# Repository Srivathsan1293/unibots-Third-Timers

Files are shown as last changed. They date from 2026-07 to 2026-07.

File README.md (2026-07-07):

Software architecture:

1. Phone handles position and long range ball detection.
2. Rasberry Pi 4 handles close range ball detection (0-20cm) and FSM communicating to both phone and ESP's
3. Encoder.ino runs on Drive_esp which handles wasd instrucitons using PID with IMU+encoder fusion.
4. Launcher.ino control launch sequence

The phone used is a pixel 7. 
The onboard TPU is used to accelerate ML inference to detect balls even 2m away.
Using focal length data and real world position the system determines robots position to a couple cm. 
Using exact position the position of balls is also estimated and shown on a map with the robot always moving towards the closest ball.

In order to maximise on day performance all variables can be adjusted quickly using a settings menu.

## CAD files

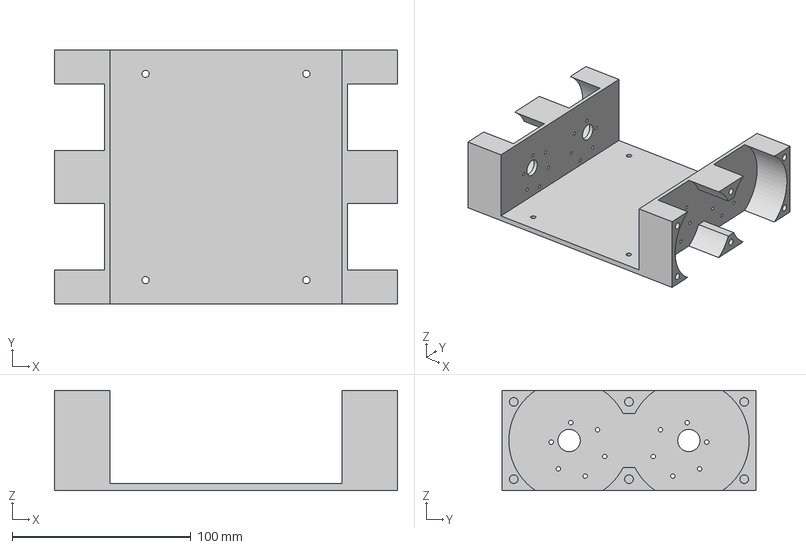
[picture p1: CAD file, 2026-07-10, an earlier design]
cad_old/early_june_prints/New Base.3mf
192.0 x 142.0 x 56.2 mm

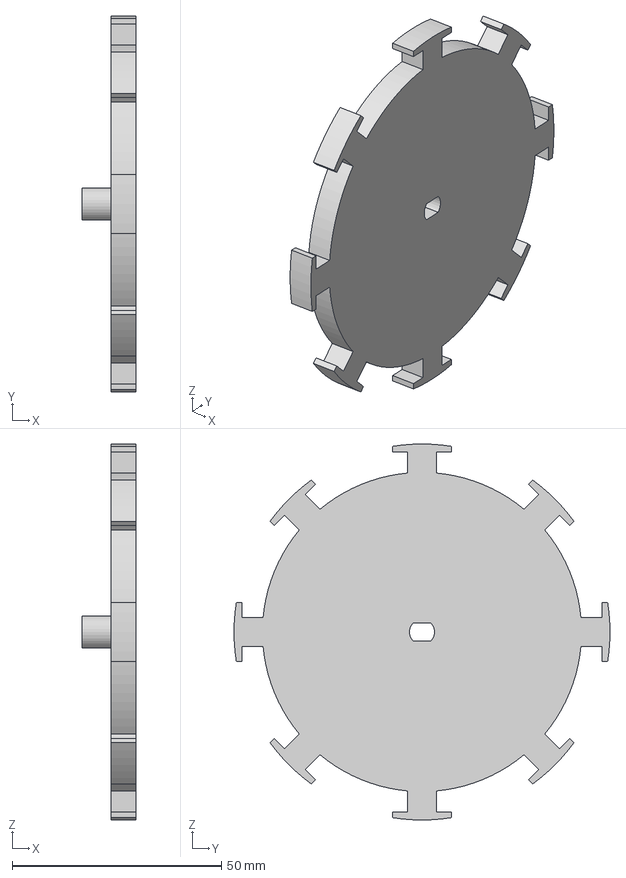
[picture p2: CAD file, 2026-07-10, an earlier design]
cad_old/late_may_prints/Spokes for Rubber Bands.3mf
13.0 x 89.9 x 89.9 mm

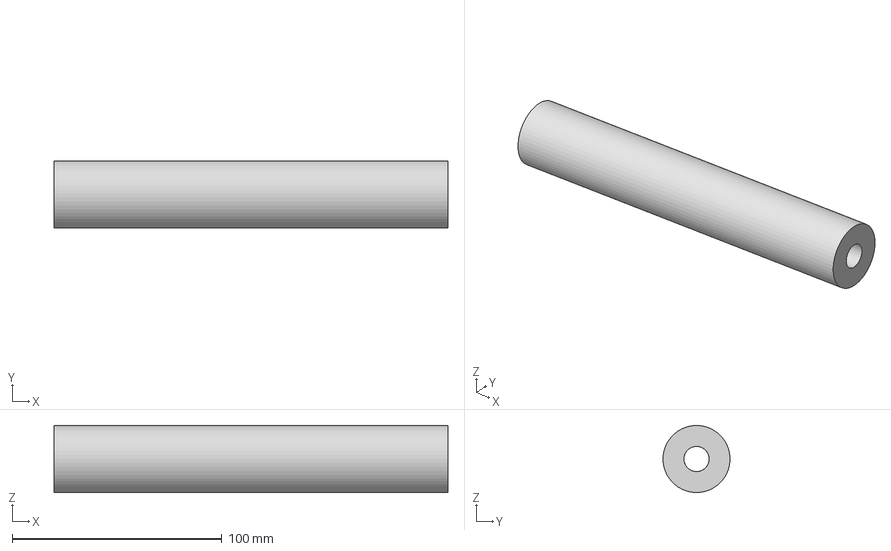
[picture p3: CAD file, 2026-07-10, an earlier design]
cad_old/middle.3mf
188.0 x 32.0 x 32.0 mm

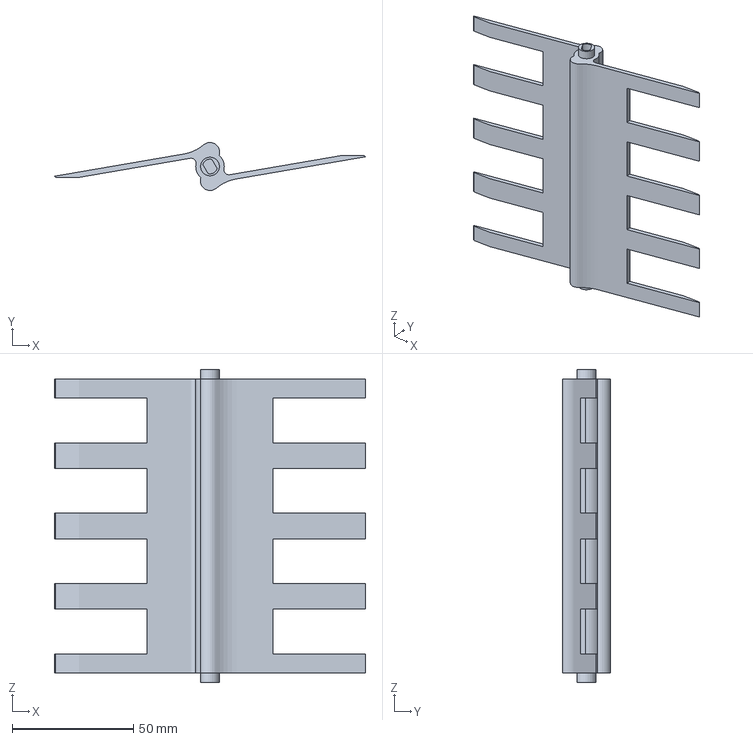
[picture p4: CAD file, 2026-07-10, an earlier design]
cad_old/early_june_prints/New Spin.3mf
128.0 x 19.8 x 129.0 mm

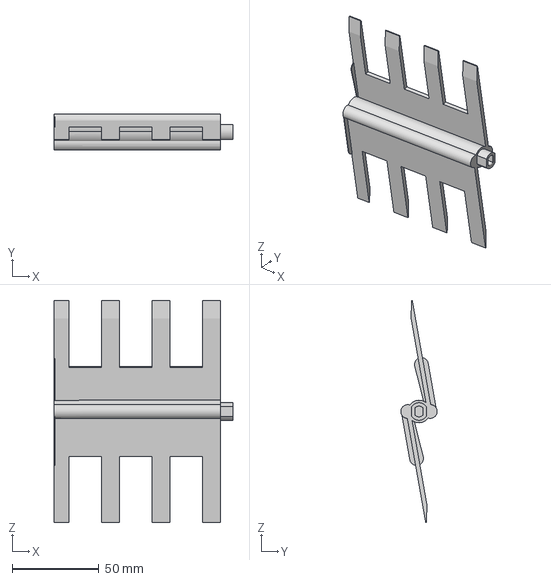
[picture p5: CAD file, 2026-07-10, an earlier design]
cad_old/late_may_prints/spin.3mf
103.0 x 21.0 x 128.0 mm

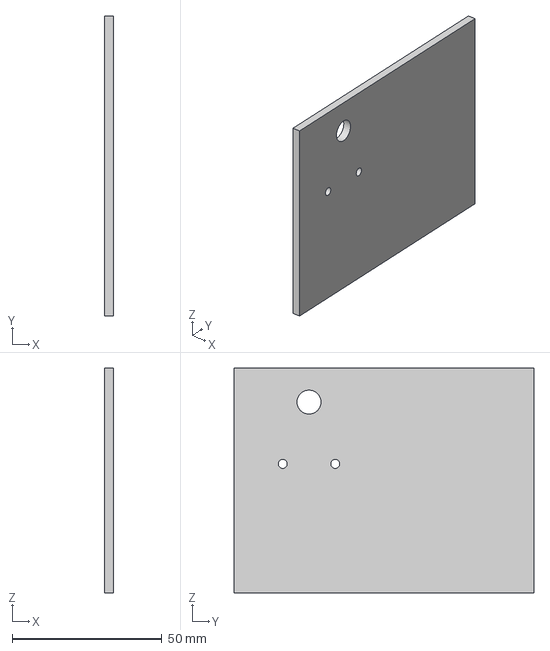
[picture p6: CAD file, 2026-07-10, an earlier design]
cad_old/Sidewall.3mf
3.00 x 100.0 x 75.0 mm

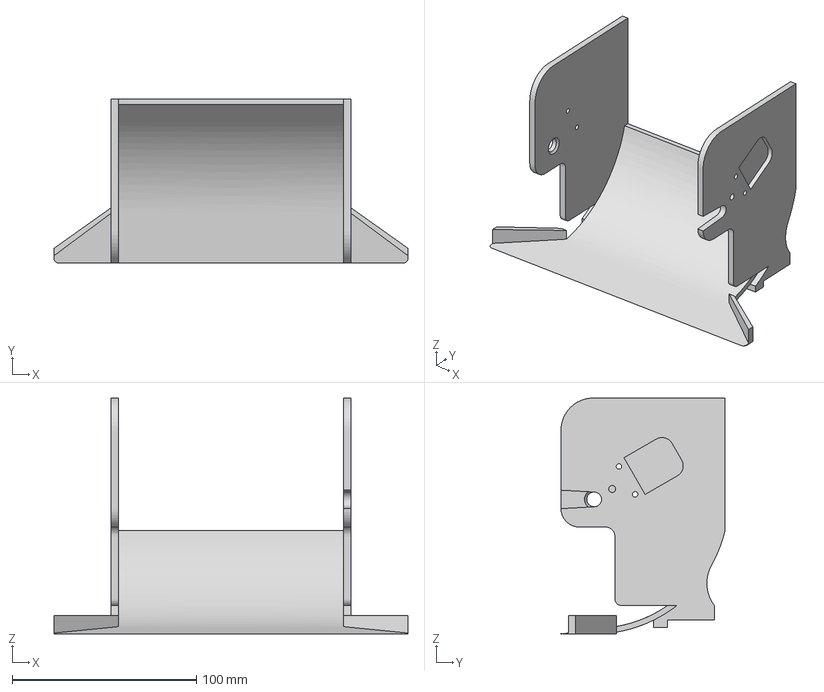
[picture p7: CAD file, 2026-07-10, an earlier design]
cad_old/early_june_prints/New Ramp.3mf
192.0 x 89.0 x 128.0 mm

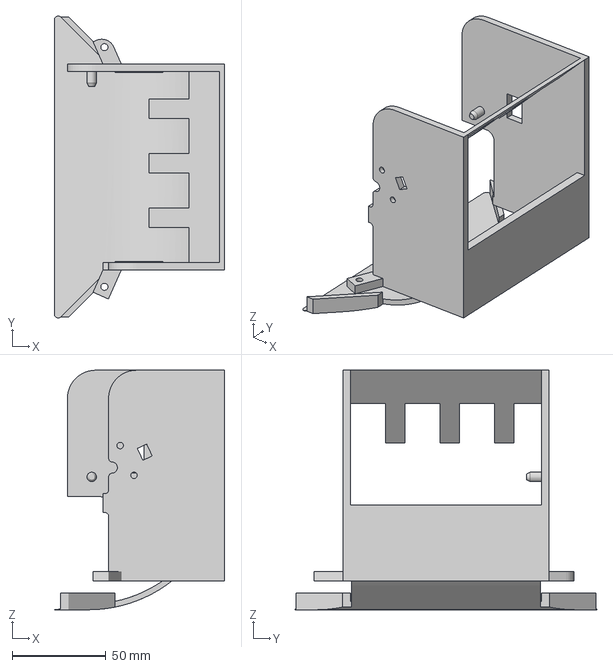
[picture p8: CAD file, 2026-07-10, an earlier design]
cad_old/late_may_prints/Slope.3mf
91.0 x 161.3 x 128.0 mm

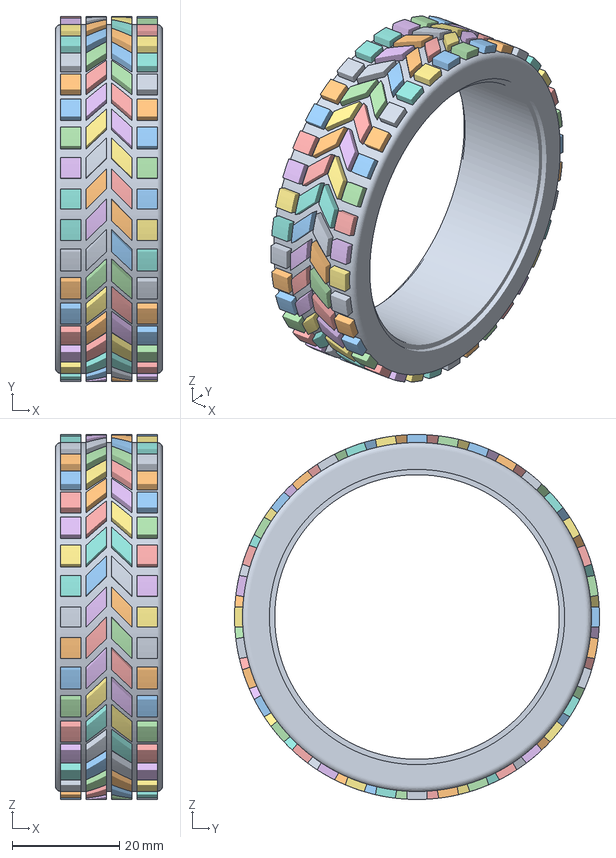
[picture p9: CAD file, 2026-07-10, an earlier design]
cad_old/Tyre.3mf
20.0 x 68.0 x 68.0 mm

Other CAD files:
cad_old/ramp-NEW_NEW.3mf
cad_old/Tyre.gcode.3mf
cad_old/Single_Tyre.gcode.3mf
cad_old/spin_new.3mf
cad_old/New Tyre.gcode.3mf

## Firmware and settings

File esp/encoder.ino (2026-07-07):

#include <Wire.h>
#include <Adafruit_MPU6050.h>
#include <Adafruit_Sensor.h>
#include <ESP32Encoder.h>

// =========================
// Pin Definitions
// =========================

// --- Drive Pins ---
const int FL_IN1 = 13, FL_IN2 = 14;
const int FR_IN2 = 12, FR_IN1 = 26; // FR_IN1 moved to 12
const int LR_IN3 = 27, LR_IN4 = 32;
const int RR_IN4 = 18, RR_IN3 = 33;

// --- PWM Pins ---
const int FL_PWM = 2;
const int FR_PWM = 5;
const int LR_PWM = 15;
const int RR_PWM = 22;

// --- Encoder Pins ---
const int FL_A = 34, FL_B = 35;
const int FR_A = 36, FR_B = 39;
const int RR_A = 4,  RR_B = 25; // RR swapped to 4 and 25
const int LR_PIN = 19;

// =========================
// PWM Setup
// =========================
const int PWM_FREQ = 20000;
const int PWM_RES_BITS = 8;

// =========================
// Encoder Objects
// =========================
ESP32Encoder encFL, encFR, encRR;
volatile long pulseCountLR = 0;

// =========================
// IMU Setup (For PID Correction ONLY)
// =========================
Adafruit_MPU6050 mpu;
float currentYaw = 17.0f; 
float gyroZOffset = 0.0f;
unsigned long lastImuTime = 0;

// =========================
// Drive State Machine & Control
// =========================
enum DriveState { STOPPED, FWD, REV, LEFT, RIGHT };
DriveState currentState = STOPPED;
DriveState pendingState = STOPPED;

float activeTargetPPS = 0.0f; 
float currentRampedPPS = 0.0f;
const float maxAccelPerLoop = 3000.0f; // Slew rate

float Kp = 0.5f;
float Ki = 0.05f;
float intFL = 0.0f, intFR = 0.0f, intLR = 0.0f, intRR = 0.0f;

float Kp_yaw = 15.0f;
float Ki_yaw = 0.0f;
float targetYaw = 0.0f;
float integralYaw = 0.0f;
bool isTurning = false;

// =========================
// Odometry (Pure Encoder Kinematics)
// =========================
float posX = 0.0f;
float posY = 0.0f;
float odomYaw = 0.0f; // New purely hardware-calculated yaw

float mmPerPulse = 0.071267f;
const float trackWidthMM = 160.0f; // Distance between left and right wheels (Update if necessary)
bool odomValid = true;

// =========================
// RTOS Sync
// =========================
TaskHandle_t ControlTaskHandle;
portMUX_TYPE rtosMux = portMUX_INITIALIZER_UNLOCKED;
portMUX_TYPE isrMux = portMUX_INITIALIZER_UNLOCKED;

// =========================
// Serial input buffer
// =========================
String serialLine = "";

// =========================
// ISR
// =========================
void IRAM_ATTR isrLR() {
  portENTER_CRITICAL_ISR(&isrMux);
  pulseCountLR++;
  portEXIT_CRITICAL_ISR(&isrMux);
}

// =========================
// Function Prototypes
// =========================
void ControlLoopTask(void * pvParameters);
void setDirections(bool fl, bool fr, bool lr, bool rr);
int getPID(float target, float current, float &i);
void writeMotorPWM(int fl, int fr, int lr, int rr);
void stopAllMotors();
float calibrateGyroZOffset();
void handleSerialInput();
void processCommand(String cmd);

// =========================
// Setup
// =========================
void setup() {
  Serial.begin(115200);
  delay(200);

  // -------------------------
  // Encoder setup
  // -------------------------
  ESP32Encoder::useInternalWeakPullResistors = puType::up;

  encFL.attachHalfQuad(FL_A, FL_B);
  encFR.attachHalfQuad(FR_A, FR_B);
  encRR.attachHalfQuad(RR_A, RR_B);

  encFL.clearCount();
  encFR.clearCount();
  encRR.clearCount();

  pinMode(LR_PIN, INPUT);
  attachInterrupt(digitalPinToInterrupt(LR_PIN), isrLR, CHANGE);

  // -------------------------
  // Motor GPIO setup
  // -------------------------
  pinMode(FL_IN1, OUTPUT); pinMode(FL_IN2, OUTPUT);
  pinMode(FR_IN1, OUTPUT); pinMode(FR_IN2, OUTPUT);
  pinMode(LR_IN3, OUTPUT); pinMode(LR_IN4, OUTPUT);
  pinMode(RR_IN3, OUTPUT); pinMode(RR_IN4, OUTPUT);

  // -------------------------
  // PWM setup
  // -------------------------
  ledcAttach(FL_PWM, PWM_FREQ, PWM_RES_BITS);
  ledcAttach(FR_PWM, PWM_FREQ, PWM_RES_BITS);
  ledcAttach(LR_PWM, PWM_FREQ, PWM_RES_BITS);
  ledcAttach(RR_PWM, PWM_FREQ, PWM_RES_BITS);

  stopAllMotors();

  // -------------------------
  // IMU setup (Strictly for immediate loop correction)
  // -------------------------
  Wire.begin(21, 23);
  if (!mpu.begin()) {
    while (1) {
      Serial.println("X:INV,Y:INV,H:0.0");
      delay(500);
    }
  }

  mpu.setGyroRange(MPU6050_RANGE_500_DEG);
  mpu.setFilterBandwidth(MPU6050_BAND_21_HZ);
  gyroZOffset = calibrateGyroZOffset();

  portENTER_CRITICAL(&rtosMux);
  currentYaw = 0.0f;
  targetYaw = 0.0f;
  integralYaw = 0.0f;
  portEXIT_CRITICAL(&rtosMux);

  lastImuTime = millis();

  // -------------------------
  // Control task on Core 0
  // -------------------------
  xTaskCreatePinnedToCore(
    ControlLoopTask,
    "ControlTask",
    4096,
    NULL,
    1,
    &ControlTaskHandle,
    0
  );
}

// =========================
// Main loop: serial + telemetry
// =========================
void loop() {
  handleSerialInput();

  static unsigned long lastTx = 0;
  if (millis() - lastTx >= 33) {
    lastTx = millis();

    float txX, txY, txH;
    bool txValid;

    portENTER_CRITICAL(&rtosMux);
    txX = posX;
    txY = posY;
    txH = odomYaw; // Broadasting encoder-derived Yaw, ignoring the IMU for position
    txValid = odomValid;
    portEXIT_CRITICAL(&rtosMux);

    if (txValid) {
      Serial.print("X:");
      Serial.print(txX, 2);
      Serial.print(",Y:");
      Serial.print(txY, 2);
      Serial.print(",H:");
      Serial.println(txH, 3);
    } else {
      Serial.print("X:INV,Y:INV,H:");
      Serial.println(txH, 3);
    }
  }
  delay(1);
}

// ==========================================
// Core 0: IMU + encoder + PID loop
// ==========================================
void ControlLoopTask(void * pvParameters) {
  TickType_t xLastWakeTime = xTaskGetTickCount();
  const TickType_t xFrequency = pdMS_TO_TICKS(33);

  for (;;) {
    // -------------------------
    // 1. IMU update (Purely for PID Correction)
    // -------------------------
    sensors_event_t a, g, temp;
    mpu.getEvent(&a, &g, &temp);

    unsigned long currentTime = millis();
    float dt_imu = (currentTime - lastImuTime) / 1000.0f;
    lastImuTime = currentTime;
    if (dt_imu < 0.0f || dt_imu > 0.2f) { dt_imu = 0.033f; }

    portENTER_CRITICAL(&rtosMux);
    currentYaw += ((g.gyro.z - gyroZOffset) * 57.2958f * dt_imu);
    while (currentYaw > 180.0f) currentYaw -= 360.0f;
    while (currentYaw < -180.0f) currentYaw += 360.0f;
    portEXIT_CRITICAL(&rtosMux);

    // -------------------------
    // 2. Encoder sampling
    // -------------------------
    long rawLR_tach;
    portENTER_CRITICAL(&isrMux);
    rawLR_tach = pulseCountLR;
    pulseCountLR = 0;
    portEXIT_CRITICAL(&isrMux);

    long rawFL = encFL.getCount();
    long rawFR = encFR.getCount();
    long rawRR = encRR.getCount();
    encFL.clearCount();
    encFR.clearCount();
    encRR.clearCount();

    int leftDirectionSign = 1;
    if (rawFL < 0) { leftDirectionSign = 1; }
    else if (rawFL > 0) { leftDirectionSign = -1; } 
    else { leftDirectionSign = (digitalRead(LR_IN3) == HIGH) ? 1 : -1; }

    const float lrTrimFactor = 1.12f;
    long virtualSignedLR = (long)((rawLR_tach * lrTrimFactor) * leftDirectionSign);
    float signedPpsFL = rawFL * 30.3f;
    float signedPpsFR = rawFR * 30.3f;
    float signedPpsLR = virtualSignedLR * 30.3f;
    float signedPpsRR = rawRR * 30.3f;

    // -------------------------
    // 3. Encoder Kinematics (Overriding IMU for mapping)
    // -------------------------
    float avgLeftPPS = (signedPpsFL + signedPpsLR) / 2.0f;
    float avgRightPPS = (signedPpsFR + signedPpsRR) / 2.0f;
    
    // Distances covered in this 33ms window
    float distLeft = avgLeftPPS * mmPerPulse * 0.033f; 
    float distRight = avgRightPPS * mmPerPulse * 0.033f;
    float distCenter = (distLeft + distRight) / 2.0f;
    
    // Hardware derived yaw change calculation
    float deltaYaw = (distRight - distLeft) / trackWidthMM;

    portENTER_CRITICAL(&rtosMux);
    odomYaw += deltaYaw;
    
    // Clamp odomYaw between -PI and PI
    while (odomYaw > PI) odomYaw -= TWO_PI;
    while (odomYaw < -PI) odomYaw += TWO_PI;

    // Apply movement over absolute vector
    posX += distCenter * cos(odomYaw);
    posY += distCenter * sin(odomYaw);

    float localCurrentYaw = currentYaw; // Maintain IMU just for error tracking
    bool localIsTurning = isTurning;
    float localTargetYaw = targetYaw;
    DriveState localPendingState = pendingState;
    float localActiveTarget = activeTargetPPS;
    portEXIT_CRITICAL(&rtosMux);

    // -------------------------
    // 4. Absolute wheel speeds
    // -------------------------
    float ppsFL = abs(signedPpsFL);
    float ppsFR = abs(signedPpsFR);
    float ppsLR = abs(signedPpsLR);
    float ppsRR = abs(signedPpsRR);

    // -------------------------
    // 5. Safe Transition & Ramping Logic
    // -------------------------
    float localTargetPPS = 0.0f;
    if (currentState != localPendingState) {
      localTargetPPS = 0.0f;
      if (currentRampedPPS <= 0.0f) {
        currentRampedPPS = 0.0f;
        currentState = localPendingState;
        intFL = intFR = intLR = intRR = 0.0f;
        integralYaw = 0.0f;

        if (currentState == FWD)        setDirections(true, true, true, true);
        else if (currentState == REV)   setDirections(false, false, false, false);
        else if (currentState == LEFT)  setDirections(false, true, false, true);
        else if (currentState == RIGHT) setDirections(true, false, true, false);
      }
    } else {
      localTargetPPS = localActiveTarget;
    }

    if (currentRampedPPS < localTargetPPS) {
      currentRampedPPS += maxAccelPerLoop;
      if (currentRampedPPS > localTargetPPS) currentRampedPPS = localTargetPPS;
    } else if (currentRampedPPS > localTargetPPS) {
      currentRampedPPS -= maxAccelPerLoop;
      if (currentRampedPPS < localTargetPPS) currentRampedPPS = localTargetPPS;
    }

    // -------------------------
    // 6. Motor control
    // -------------------------
    if (currentRampedPPS == 0.0f && currentState == STOPPED) {
      stopAllMotors();
      intFL = intFR = intLR = intRR = 0.0f;
      integralYaw = 0.0f;
    } else {
      float targetLeft = currentRampedPPS;
      float targetRight = currentRampedPPS;
      
      // Use IMU for instantaneous PID balancing
      if (!localIsTurning) {
        float errorYaw = localTargetYaw - localCurrentYaw;
        while (errorYaw > 180.0f) errorYaw -= 360.0f;
        while (errorYaw < -180.0f) errorYaw += 360.0f;

        integralYaw += errorYaw;
        integralYaw = constrain(integralYaw, -1000.0f, 1000.0f);

        float yawCorrection = (Kp_yaw * errorYaw) + (Ki_yaw * integralYaw);

        targetLeft = currentRampedPPS - yawCorrection;
        targetRight = currentRampedPPS + yawCorrection;
      } else {
        integralYaw = 0.0f;
      }

      targetLeft = constrain(targetLeft, 0.0f, 80000.0f);
      targetRight = constrain(targetRight, 0.0f, 80000.0f);

      int pwmFL = getPID(targetLeft, ppsFL, intFL);
      int pwmFR = getPID(targetRight, ppsFR, intFR);
      int pwmLR = getPID(targetLeft, ppsLR, intLR);
      int pwmRR = getPID(targetRight, ppsRR, intRR);

      writeMotorPWM(pwmFL, pwmFR, pwmLR, pwmRR);
    }

    vTaskDelayUntil(&xLastWakeTime, xFrequency);
  }
}

// ==========================================
// Helpers
// ==========================================
float calibrateGyroZOffset() {
  sensors_event_t a, g, temp;
  const int samples = 1500;
  float sumZ = 0.0f;

  delay(1000);
  for (int i = 0; i < samples; i++) {
    mpu.getEvent(&a, &g, &temp);
    sumZ += g.gyro.z;
    delay(2);
  }

  return sumZ / samples;
}

void handleSerialInput() {
  while (Serial.available() > 0) {
    char c = (char)Serial.read();
    if (c == 'W' || c == 'w' ||
        c == 'A' || c == 'a' ||
        c == 'S' || c == 's' ||
        c == 'D' || c == 'd' ||
        c == '0' ||
        c == 'Z' || c == 'z') {
      processCommand(String(c));
      serialLine = "";
    }
    else if (c == '\n' || c == '\r') {
      if (serialLine.length() > 0) {
        processCommand(serialLine);
        serialLine = "";
      }
    }
    else {
      serialLine += c;
      if (serialLine.length() > 64) {
        serialLine = "";
      }
    }
  }
}

void processCommand(String cmd) {
  cmd.trim();

  portENTER_CRITICAL(&rtosMux);
  if (cmd.equalsIgnoreCase("W")) {
    targetYaw = currentYaw;
    isTurning = false;
    activeTargetPPS = 80000.0f;
    pendingState = FWD;
  }
  else if (cmd.equalsIgnoreCase("S")) {
    targetYaw = currentYaw;
    isTurning = false;
    activeTargetPPS = 80000.0f;
    pendingState = REV;
  }
  else if (cmd.equalsIgnoreCase("A")) {
    isTurning = true;
    activeTargetPPS = 40000.0f;
    pendingState = LEFT;
  }
  else if (cmd.equalsIgnoreCase("D")) {
    isTurning = true;
    activeTargetPPS = 40000.0f;
    pendingState = RIGHT;
  }
  else if (cmd.equals("0")) {
    activeTargetPPS = 0.0f;
    pendingState = STOPPED;
  }
  else if (cmd.equalsIgnoreCase("Z")) {
    currentYaw = 0.0f;
    targetYaw = 0.0f;
    integralYaw = 0.0f;
  }
  // NEW FUSED POSITION COMMAND PARSER: P<X>,<Y>,<YAW>
  else if (cmd.startsWith("P") || cmd.startsWith("p")) {
    int commaIndex1 = cmd.indexOf(',');
    int commaIndex2 = cmd.indexOf(',', commaIndex1 + 1);
    
    if (commaIndex1 > 1 && commaIndex2 > commaIndex1) {
      String xStr = cmd.substring(1, commaIndex1);
      String yStr = cmd.substring(commaIndex1 + 1, commaIndex2);
      String yawStr = cmd.substring(commaIndex2 + 1);

      posX = xStr.toFloat();
      posY = yStr.toFloat();
      odomYaw = yawStr.toFloat();
      odomValid = true;
    }
  }

  portEXIT_CRITICAL(&rtosMux);
}

void setDirections(bool fl, bool fr, bool lr, bool rr) {
  digitalWrite(FL_IN1, !fl); digitalWrite(FL_IN2,  fl);
  digitalWrite(FR_IN1,  fr); digitalWrite(FR_IN2, !fr);
  digitalWrite(LR_IN3,  lr); digitalWrite(LR_IN4, !lr);
  digitalWrite(RR_IN3,  rr); digitalWrite(RR_IN4, !rr);
}

int getPID(float target, float current, float &i) {
  float err = target - current;
  i += err;
  i = constrain(i, -1000.0f, 1000.0f);

  float output = (Kp * err) + (Ki * i);
  output = constrain(output, 0.0f, 255.0f);
  return (int)output;
}

void writeMotorPWM(int fl, int fr, int lr, int rr) {
  fl = constrain(fl, 0, 255);
  fr = constrain(fr, 0, 255);
  lr = constrain(lr, 0, 255);
  rr = constrain(rr, 0, 255);

  ledcWrite(FL_PWM, fl); ledcWrite(FR_PWM, fr);
  ledcWrite(LR_PWM, lr); ledcWrite(RR_PWM, rr);
}

void stopAllMotors() {
  ledcWrite(FL_PWM, 0); ledcWrite(FR_PWM, 0);
  ledcWrite(LR_PWM, 0); ledcWrite(RR_PWM, 0);
}

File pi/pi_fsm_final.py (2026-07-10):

"""
pi_fsm_hybrid.py

Combined FSM and Communication Control.
Integrates the advanced behavior states (RETURN, APPROACH_BOX, Obstacle Avoidance) 
with the robust ADB-tunneled network link and verbose serial logging.
"""

import json
import math
import threading
import time
import subprocess
import cv2
import serial
import numpy as np
from detection import PiBallNavigator

GRAVITY = 9.81


def white_fraction(frame, thresh=180):
    """Fraction of pixels that are bright and roughly neutral (white floor).
    frame is an OpenCV BGR uint8 array. A pixel counts as white when all three
    channels are >= thresh. Returns 0.0..1.0; 1.0 means a fully clear white view.
    """
    if frame is None:
        return 1.0
    arr = np.asarray(frame)
    if arr.ndim != 3:
        return 1.0
    white = np.all(arr >= thresh, axis=2)
    return float(white.mean())


# ── physics ────────────────────────────────────────────────────────────────
def compute_launch_speed(distance_m, angle_rad, height_diff_m, g=GRAVITY):
    c = math.cos(angle_rad)
    drop = distance_m * math.tan(angle_rad) - height_diff_m
    denom = 2.0 * c * c * drop
    if denom <= 0:
        return None
    return math.sqrt(g * distance_m * distance_m / denom)


def spring_setting(speed, k=8.0, offset=0.0, lo=0, hi=255):
    if speed is None:
        return None
    return max(lo, min(hi, int(round(offset + k * speed * speed))))


def _wrap(a):
    return math.atan2(math.sin(a), math.cos(a))


# ── transport ──────────────────────────────────────────────────────────────
class DriveESP:
    def __init__(self, port="/dev/ttyUSB_DRIVE", baud=115200):
        self.ser = serial.Serial(port, baud, timeout=0.05)
        self.last_cmd = None

    def send(self, cmd, current_state):
        if cmd != self.last_cmd:
            print(f"[{current_state.upper()}] -> Sending to DRIVE ESP: '{cmd}'")
            self.ser.write(f"{cmd}\n".encode())
            self.last_cmd = cmd


class LauncherESP:
    def __init__(self, port="/dev/ttyUSB_LAUNCHER", baud=115200):
        self.ser = serial.Serial(port, baud, timeout=0.05)
        self._last = ""

    def tension(self, setting, current_state):
        print(f"[{current_state.upper()}] -> Sending to LAUNCHER ESP: 'T,{setting}' (Tensioning)")
        self.ser.write(f"T,{setting}\n".encode())

    def release(self, current_state):
        print(f"[{current_state.upper()}] -> Sending to LAUNCHER ESP: 'RELEASE' (Firing)")
        self.ser.write(b"RELEASE\n")

    def _poll(self):
        line = self.ser.readline().decode(errors="ignore").strip()
        if line:
            self._last = line
        return self._last

    def is_ready(self):
        return self._poll() == "READY"

    def is_reset(self):
        return self._poll() == "RESET"


class PhoneLink:
    def __init__(self, host="0.0.0.0", port=5000):
        self._latest = None
        self._lock = threading.Lock()
        self._host, self._port = host, port

    def start(self):
        threading.Thread(target=self._serve, daemon=True).start()

    def _apply_adb_tunnel(self):
        try:
            result = subprocess.run(['adb', 'devices'], capture_output=True, text=True)
            if '\tdevice' in result.stdout:
                subprocess.run(['adb', 'reverse', f'tcp:{self._port}', f'tcp:{self._port}'], check=True)
                return True
            return False
        except FileNotFoundError:
            print("Error: 'adb' utility not found on this system.")
            return False

    def _serve(self):
        import socket
        srv = socket.socket(socket.AF_INET, socket.SOCK_STREAM)
        srv.setsockopt(socket.SOL_SOCKET, socket.SO_REUSEADDR, 1)
        srv.bind((self._host, self._port))
        srv.settimeout(2.0)
        srv.listen(1)
        
        while True:
            if not self._apply_adb_tunnel():
                time.sleep(2)
                continue
                
            try:
                conn, _ = srv.accept()
                conn.settimeout(None) 
                buf = ""
                with conn:
                    while True:
                        data = conn.recv(4096)
                        if not data:
                            break
                        buf += data.decode(errors="ignore")
                        while "\n" in buf:
                            line, buf = buf.split("\n", 1)
                            line = line.strip()
                            if line.startswith("NAV,"):
                                parts = line.split(",")
                                if len(parts) >= 5:
                                    try:
                                        msg = {
                                            "dir": parts[1],
                                            "x": float(parts[2]),
                                            "y": float(parts[3]),
                                            "yaw": float(parts[4])
                                        }
                                        with self._lock:
                                            self._latest = msg
                                    except ValueError:
                                        continue
            except socket.timeout:
                pass
            except (ConnectionResetError, BrokenPipeError):
                pass

    def latest(self):
        with self._lock:
            return dict(self._latest) if self._latest else None
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

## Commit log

2026-07-10 initial commit calibration code
2026-07-10 Initial commit esp control motor
2026-07-10 ADded old CAD files from USBs & date last modified as csv
    [New Base.3mf, New Ramp.3mf, New Spin.3mf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]
